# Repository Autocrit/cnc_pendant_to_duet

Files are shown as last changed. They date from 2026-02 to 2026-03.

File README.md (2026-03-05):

# CNC Pendant D-Sub connector to Duet PCB

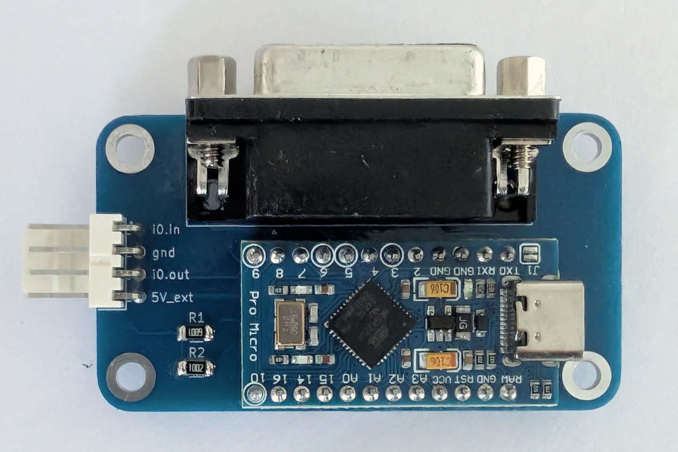
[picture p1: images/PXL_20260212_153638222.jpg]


## Overview

The aim for this PCB was to simplify the connection of a CNC pendant to a Duet 2 or 3, and to provide a disconnect at the electronics enclosure.

It follows the wiring diagram and instructions at [Duet3D CNC Pendant Documentation](https://docs.duet3d.com/User_manual/Connecting_hardware/IO_CNC_Pendant).

## Notes

1. Other CNC pendants may have different pin arrangements. Some differences could be fixed in firmware; others only by modifying the PCB.
1. This PCB was tested with a Duet 3, but not with a Duet 2 or a PanelDue.
1. There is a small change needed to the Arduino firmware. 
1. I don't know what I'm doing. Use at your own risk.
1. There's a pin labelled *iO.out* on the PCB in these photos. That's a mistake and its corrected to *dout* in the KiCad project.

## Ordering

Production files are at `./kicad/production/cnc_pendant_to_duet.zip`. In February 2026, 5 boards from JLCPCB cost £3.60 including VAT and delivery to the UK.

## Choice of CNC pendant

I have [this](https://www.aliexpress.com/item/32847286243.html) pendant from [Rattm Motor Store](https://www.aliexpress.com/store/907217) on Aliexpress (the listing says 4-axis but the one I received is 5-axis).

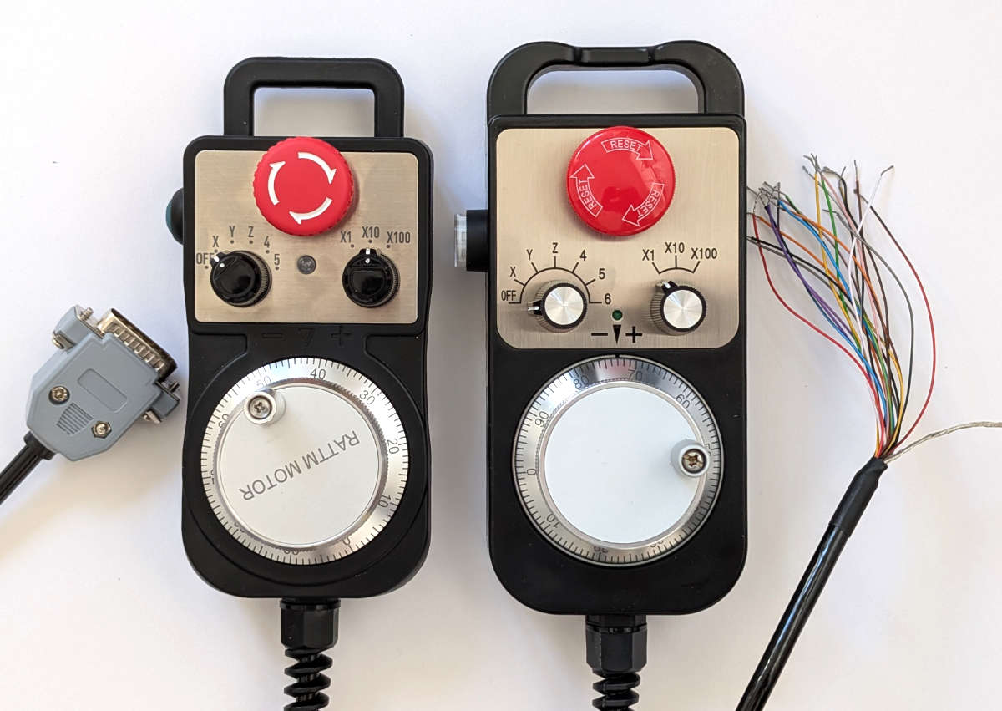
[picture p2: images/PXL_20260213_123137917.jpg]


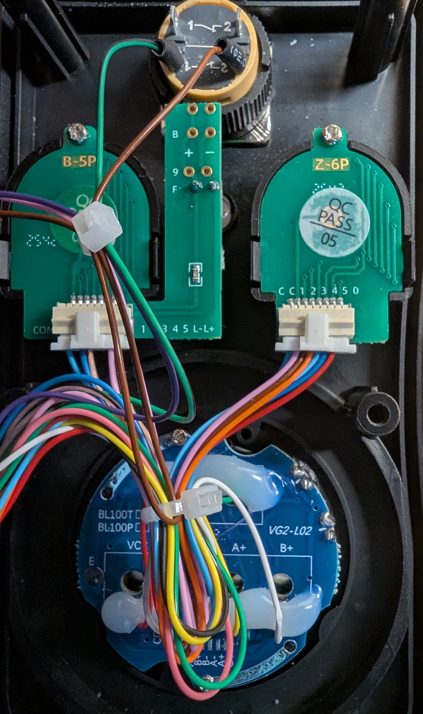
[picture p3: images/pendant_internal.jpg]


### D-Sub pins

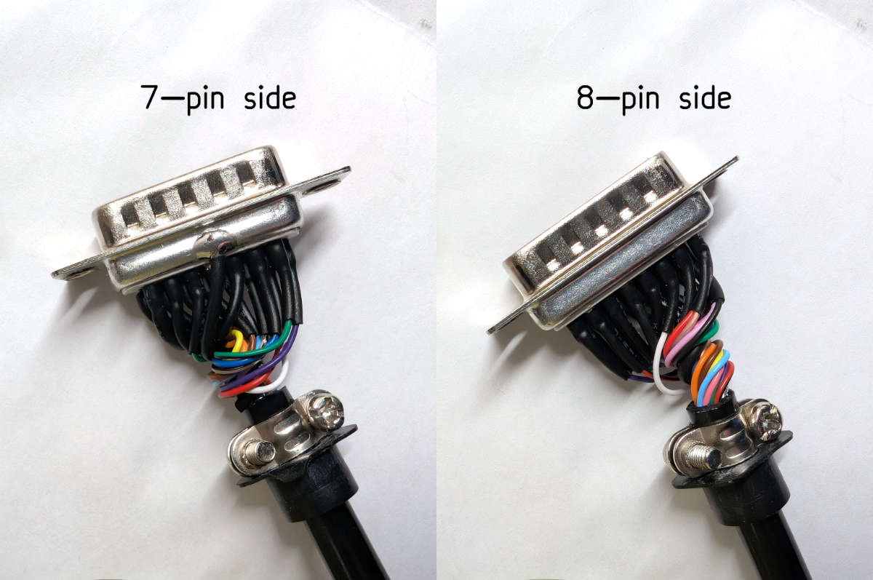
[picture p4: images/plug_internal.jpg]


The image below shows a female socket as you look at it:

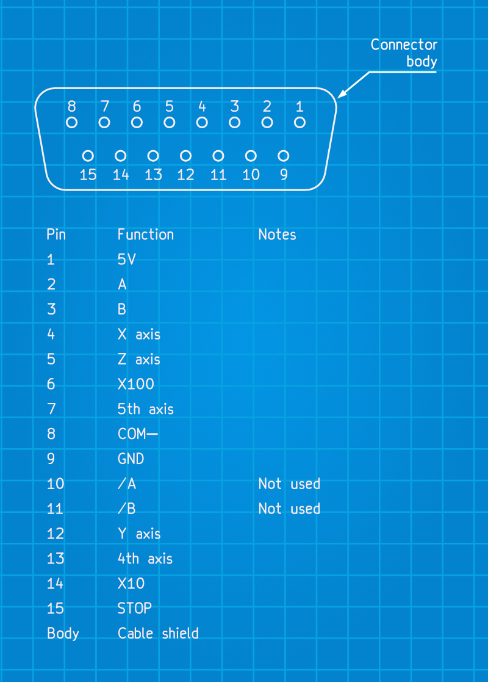
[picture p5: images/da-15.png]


GND, COM-, and shield are all connected to ground on the PCB.

The connector pinout can be checked against the pads in the pendant.

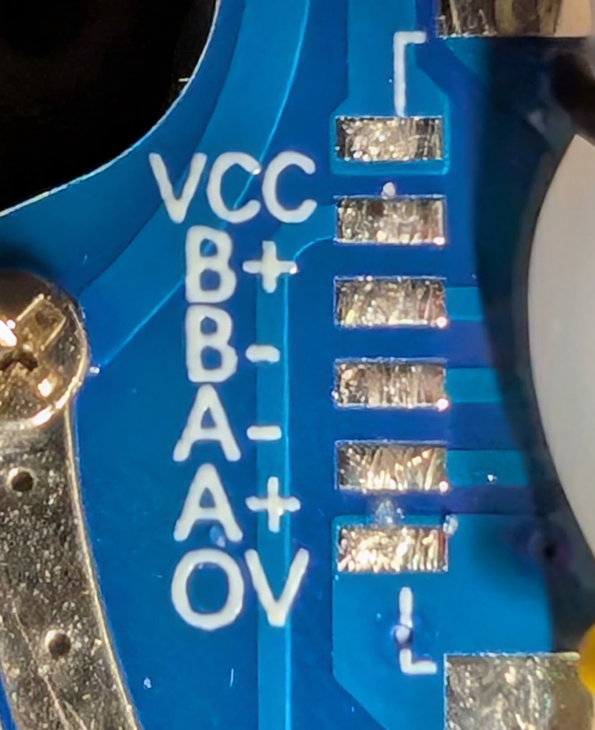
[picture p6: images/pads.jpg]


## Mounting

The PCB can be mounted to the inside of an enclosure using the hex studs of the D‑sub connector. Alternatively, it could be mounted internally with an extension cable.

### Cutout

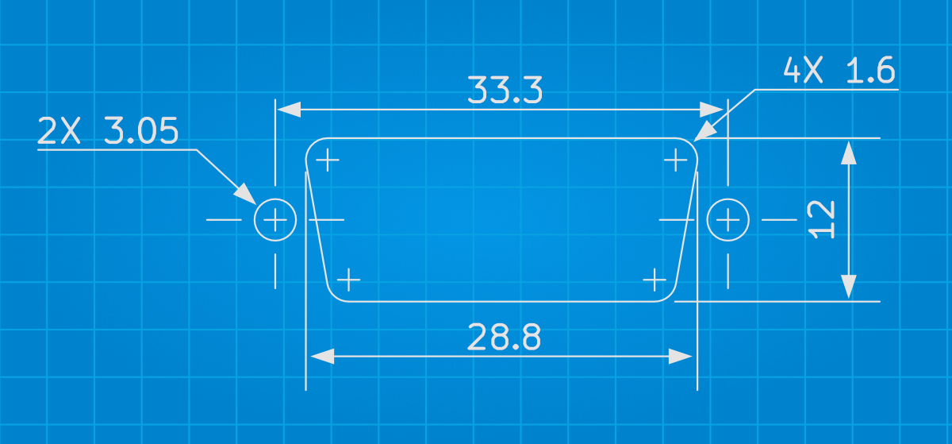
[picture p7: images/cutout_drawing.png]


[DXF](./cad/panel_cutout.dxf)
[PDF](./cad/panel_cutout.pdf)

### PCB dimensions and hole spacing

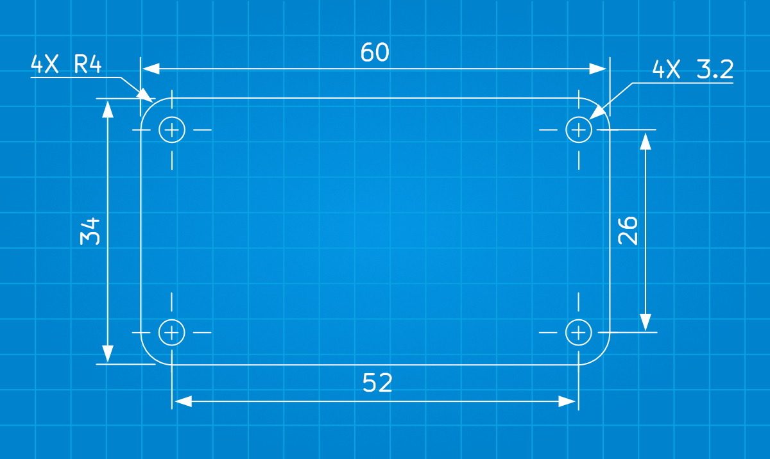
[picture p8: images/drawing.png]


## Components

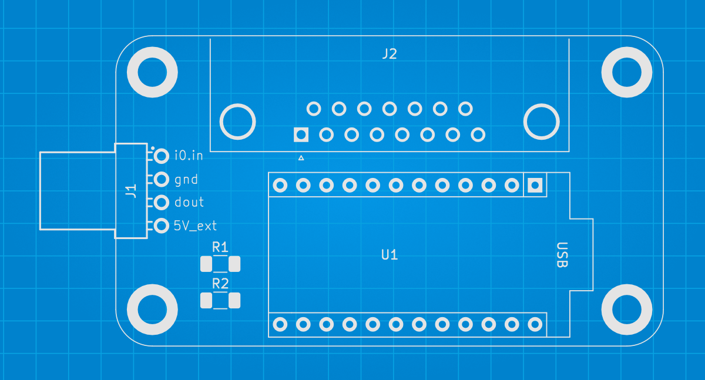
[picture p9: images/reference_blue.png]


| Reference | Description |
|--- | --- |
| U1 | Arduino Pro Micro |
| R1 | 1206 SMD 6K8 (6.8kΩ) resistor |
| R2 | 1206 SMD 10K (10kΩ) resistor |
| J1 | 1x4 2.54mm pitch male right-angle (optional) header |
| J2 | 15-pin D-Sub female right-angle (optional) connector with hex screws |

### Arduino Pro Micro (U1)

Use 2 1x12 female headers if the Arduino should be removable.

### Resistors (R1 & R2)

The resistors are optional when connecting to a Duet 3. If omitted, the pads of R1 should be bridged (see image).

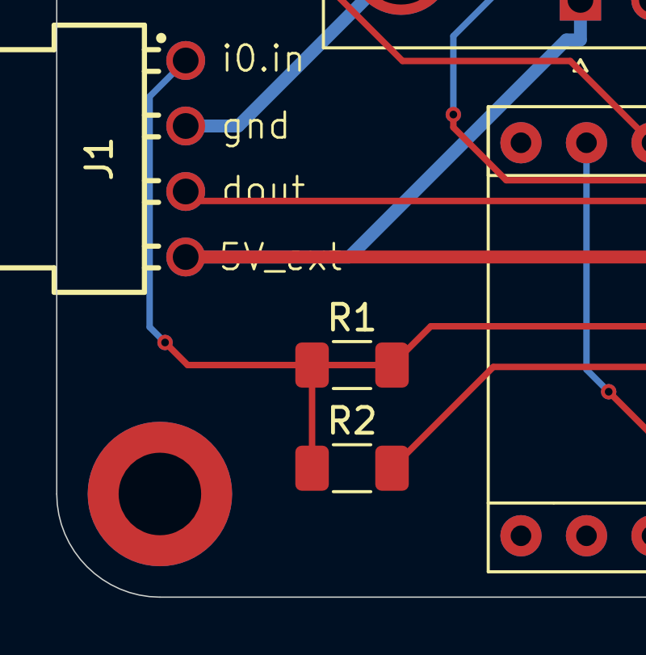
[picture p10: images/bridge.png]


### 1x4 header (J1)

The 1x4 pin 2.54mm pitch male header for connecting to a Duet 2 or 3 can be any make or type; a right-angle connector keeps the height low.

Examples are Würth Elektronik WR-WTB [61900411121](https://www.we-online.com/en/components/products/WTB_WR_WTB_2_54_MALE#61900411121) (vertical), 
Würth Elektronik WR-WTB [61900411021](https://www.we-online.com/en/components/products/WTB_WR_WTB_2_54_MALE#61900411021) (horizontal) or Würth Elektronik WR-WTB [61900419521](https://www.we-online.com/en/components/products/WTB_WR_WTB_2_54_MALE#61900419521) (also horizontal).

KF2510 connectors are a cheaper alternative.

### D-Sub connector (J2)

e.g. Würth Elektronik WR-DSUB PCB [618015231121](https://www.we-online.com/en/components/products/INPUT_OUTPUT_WR_DSUB_CONNECTORS_PCB#618015231121).

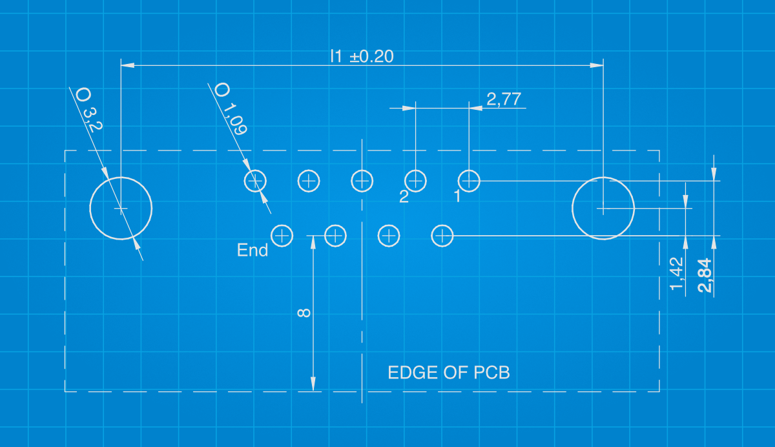
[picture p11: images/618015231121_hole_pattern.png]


The mounting‑hole‑to‑board‑edge dimension appears to be a common one; cheaper connectors from, for example, Ebay seem fine.

## Connecting to Duet 2 or 3

This image shows the PCB connected to io.0 on a Duet 3.
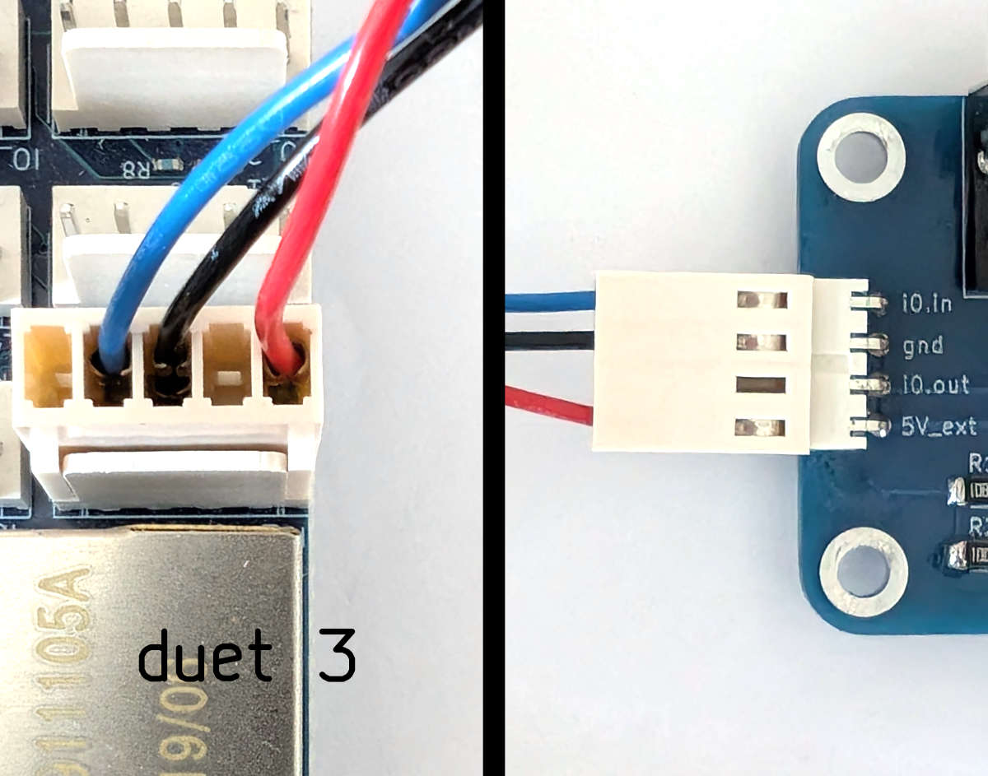
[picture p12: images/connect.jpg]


See [Connector and spare part numbers](https://docs.duet3d.com/User_manual/Troubleshooting/Parts).

Würth Elektronik WR-WTB 4-pin [61900411621](https://www.we-online.com/en/components/products/WTB_2_54_FEMALE_TERMINAL_HOUSING_6190XX11621#61900411621), Würth Elektronik WR-WTB 5-pin [61900511621](https://www.we-online.com/en/components/products/WTB_2_54_FEMALE_TERMINAL_HOUSING_6190XX11621#61900511621) and Würth Elektronik WR-WTB female crimp [61900113722DEC](https://www.we-online.com/en/components/products/WTB_2_54_FEMALE_CRIMP_CONTACT_619X0113722#61900113722DEC).

## Firmware

### Firmware change

In `CNC-pendant.ino`, change line 221 to:
```
distanceMultiplier = 1;
```

The reason for this is that there is no X1 pin (or signal) and the code is unable to detect that X1 is selected. Initialising `distanceMultiplier` to `1` instead of `0` solves that.

Note that the firmware is unable to control the pendant's LED (for example, to turn it off on an emergency stop) because there is no LED+ signal.

## Config

The Duet3D pendant documentation doesn't mention that serial communication needs to be enabled on io0 on Duet 3. For example:
```
; Accessories
M575 P1 S1 B57600 ; CNC pendant support
```

## Modifying the PCB for a different pinout

Anyone familiar with KiCad or PCB design should ignore this.
1. In the Schematic Editor, change labels on the DA-15 socket as necessary.
1. In the PCB Editor, *Tools->Update PCB from Schematic...*
1. Delete all vias and tracks with *Edit->Global Deletions...->Tracks & vias*
1. I would then cheat and use the *Freerouting* plugin, followed by some clean up (it  leaves unconnected tracks and other easily-fixed issues).
1. Use *Inspect->Design Rules Checker* to help find problems.
1. I used the *Fabrication Toolkit* plugin to generate files for JLCPCB. As its going to be an unassembled board, only the ZIP file is important.

I can help if you know the pinout but don't want to dive into KiCad.

## Adding a D-Sub connector to the "standard" CNC pendant

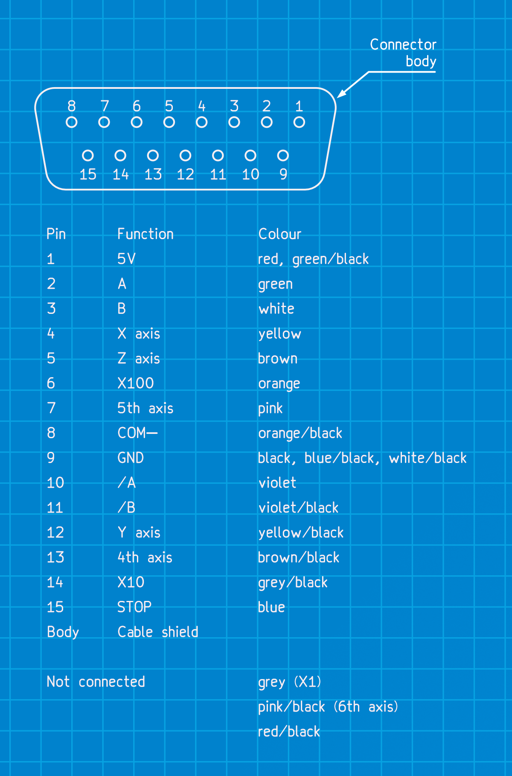
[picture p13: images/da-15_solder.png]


## TODO
- test with Duet 2
- test with PanelDue 
- test with more than one CNC pendant
- add pins for PanelDue wiring (if that would be useful)

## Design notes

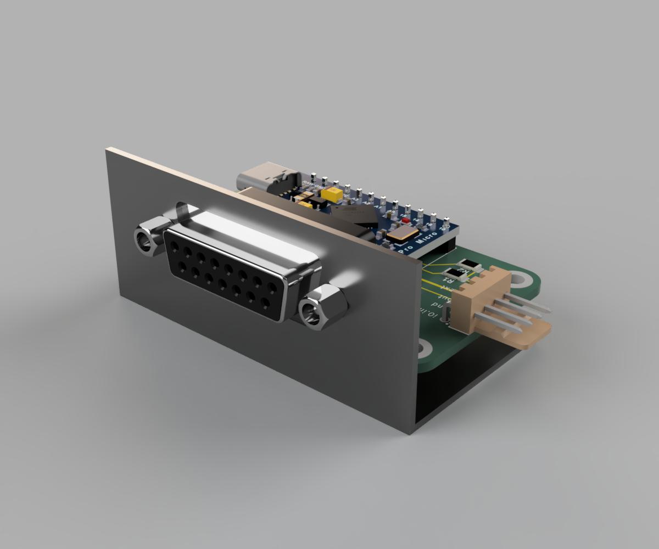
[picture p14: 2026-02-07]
images/dA-15_cutout.jpg

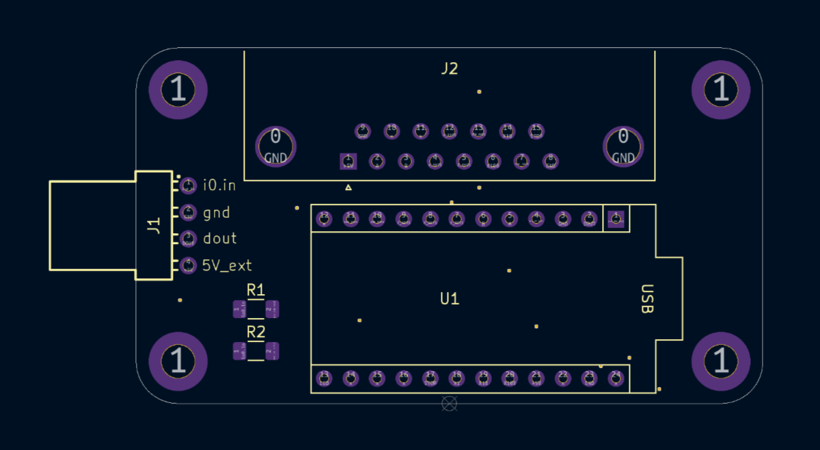
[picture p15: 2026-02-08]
images/reference.png

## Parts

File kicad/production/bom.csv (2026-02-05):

Designator | Footprint | Quantity | Value | LCSC Part #
J1 | 61900411021 | 1 | Conn_01x04_Male
J2 | DSUB-15_Socket_Horizontal_P2.77x2.84mm_EdgePinOffset7.70mm_Housed_MountingHolesOffset9.12mm | 1 | DA15_Socket_MountingHoles
R1 | 1206 | 1 | 6K8
R2 | 1206 | 1 | 10K
U1 | Sparkfun_Pro_Micro | 1 | Sparkfun_Pro_Micro

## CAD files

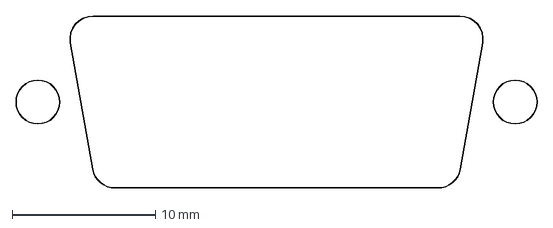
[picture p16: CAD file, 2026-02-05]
cad/panel_cutout.dxf
36.4 x 12.0 mm

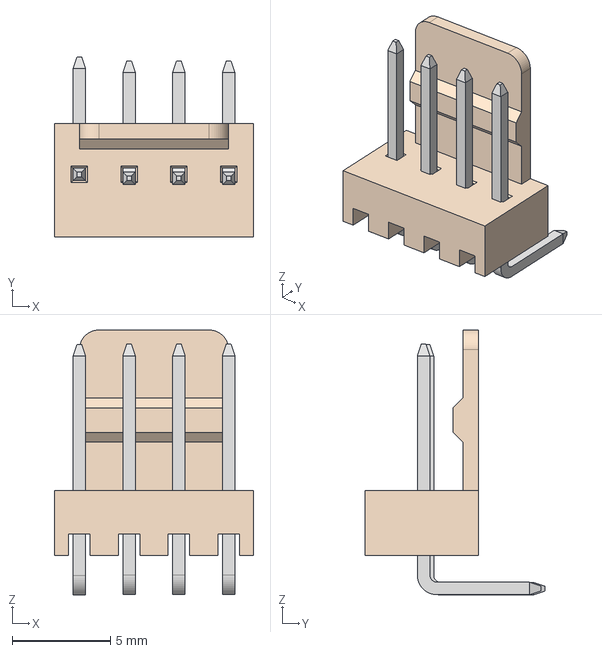
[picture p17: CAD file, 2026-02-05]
kicad/3d_models/61900411021.step
10.2 x 9.20 x 13.5 mm
6190xx1xx21_PIN x 4

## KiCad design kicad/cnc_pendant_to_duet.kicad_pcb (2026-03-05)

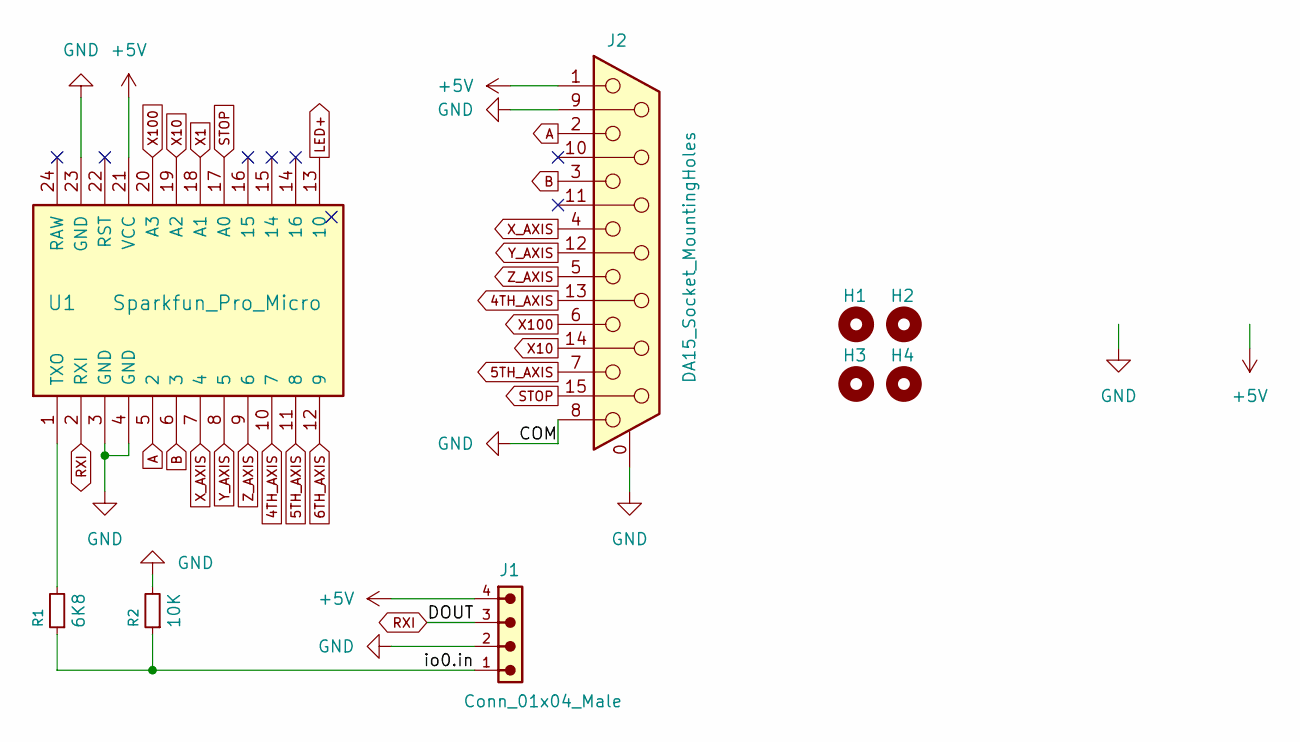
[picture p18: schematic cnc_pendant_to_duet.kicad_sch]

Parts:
H1, H2, H3, H4: MountingHole; MountingHole_3.2mm_M3_DIN965_Pad
J1: Conn_01x04_Male; 61900411021
J2: DA15_Socket_MountingHoles; DSUB-15_Socket_Horizontal_P2.77x2.84mm_EdgePinOffset7.70mm_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
R1: 6K8; R_1206_3216Metric_Pad1.30x1.75mm_HandSolder
R2: 10K; R_1206_3216Metric_Pad1.30x1.75mm_HandSolder
U1: Sparkfun_Pro_Micro

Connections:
4TH_AXIS: J2.13, U1.10 (7)
5TH_AXIS: J2.7, U1.11 (8)
6TH_AXIS: U1.12 (9)
+5V: J1.4, J2.1, U1.21 (VCC)
/io0.in: J1.1, R1.1, R2.1
A: J2.2, U1.5 (2)
B: J2.3, U1.6 (3)
GND: J1.2, J2.0 (PAD), J2.8, J2.9, R2.2, U1.3 (GND), U1.4 (GND), U1.23 (GND)
LED+: U1.13 (10)
unnamed: R1.2, U1.1 (TXO)
RXI: J1.3, U1.2 (RXI)
STOP: J2.15, U1.17 (A0)
X1: U1.18 (A1)
X10: J2.14, U1.19 (A2)
X100: J2.6, U1.20 (A3)
X_AXIS: J2.4, U1.7 (4)
Y_AXIS: J2.12, U1.8 (5)
Z_AXIS: J2.5, U1.9 (6)

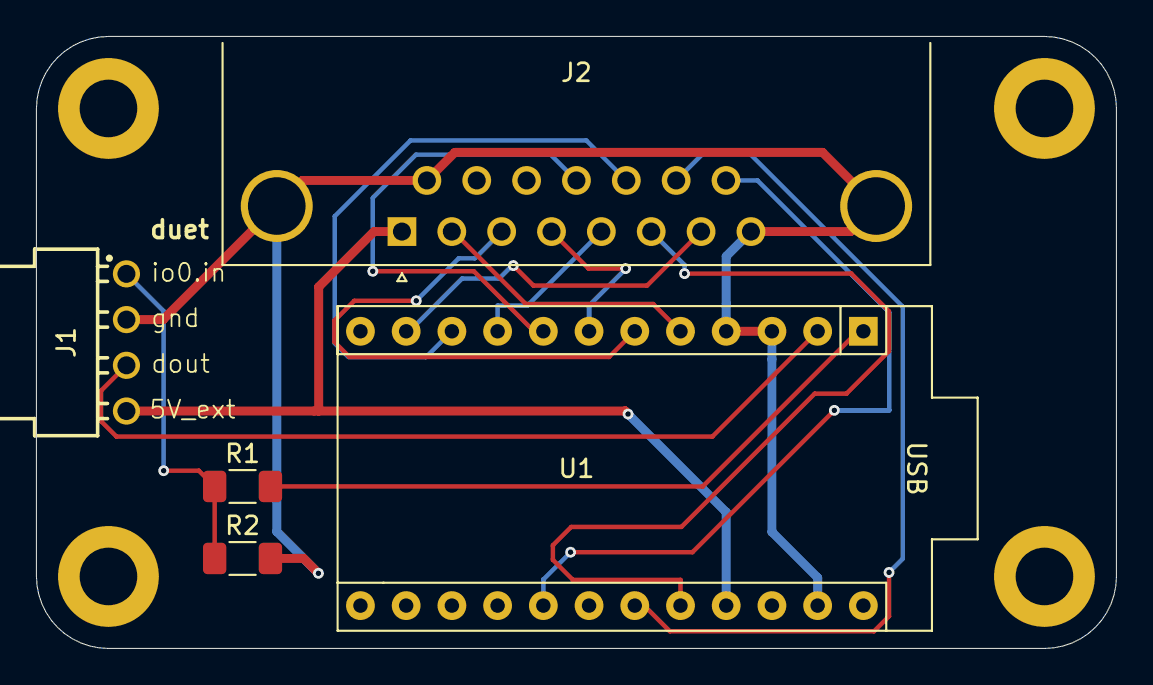
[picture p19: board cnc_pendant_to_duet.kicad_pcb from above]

Board: 2 copper layers, 60.0 x 34.0 mm, 9 parts (0 on the bottom side), 15 nets.

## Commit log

2026-02-05 KiCad initial commit
    [61900411021.step, bom.csv, cnc_pendant_to_duet3D.kicad_pcb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]
2026-02-06 Confusion over connecting to Duet and PanelDue
    Change to silkscreens
    [cnc_pendant_to_duet3d.kicad_pcb, cnc_pendant_to_duet3d.kicad_sch]
2026-02-07 production files
    [cnc_pendant_to_duet3d.kicad_pcb]
2026-02-11 10k resistor and Arduino pin 4 to GND
    PCB not updated from schematic at this point
    [cnc_pendant_to_duet3d.kicad_sch]
2026-02-15 Switched to global labels in schematic. Updated PCB
    Not tested
    [cnc_pendant_to_duet3d.kicad_pcb, cnc_pendant_to_duet3d.kicad_sch]
2026-02-15 Corrected i0.in to io0.in on silkscreen
    Regenerated production files
    [cnc_pendant_to_duet3d.kicad_pcb]
2026-02-15 Silkscreen text fixes. Regenerated production files
    [cnc_pendant_to_duet3d.kicad_pcb]
2026-03-05 Rename to cnc_pendant_to_duet
    [cnc_pendant_to_duet.kicad_pcb, cnc_pendant_to_duet.kicad_sch, cnc_pendant_to_duet3d.kicad_pcb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]
